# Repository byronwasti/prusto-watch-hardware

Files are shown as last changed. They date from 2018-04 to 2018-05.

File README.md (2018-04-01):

# Prusto Watch Hardware
Hardware for the Prusto Watch

# Update Log

## 0.3.0
- Chip now has USB functionality
- Moved to an accelerometer instead of an IMU
- New PMIC chip
- Smaller layout with mounting holes

## 0.2.0
- Chip selected has no USB functionality
- LEDs work
- Battery connector is incorrect
- BLE is functional
- Display connector is flipped (must be soldered on backwards)

## 0.1.0
- Poor debuggability
- BLE connectivity
- IMU routing
- LED
- Display

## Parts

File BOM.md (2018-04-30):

# Prusto Watch BOM

Manufacturer Part Number | Description | Digikey | Count | Price
:---|:---|:---|---: | ---:
RJD3032HPPV30M | Battery | 1572-1623-ND | 1 | 16.71 
Molex 0532610271 | Battery Connector | WM7620CT-ND | 1 | 0.93
MCP73831T-2ACI/OT | Battery Charger | MCP73831T-2ACI/OT | 1 | 0.59
TPS2113ADRBR | Power Multiplexer | 296-46373-1-ND | 1 | 2.01
TPS70933DBVR | 3.3V Voltage Regulator | 296-35483-1-ND | 1 |  1.17
LS010B7DH01 | OLED Screen | 425-2899-ND | 1 | 22.88
Molex LLC 5034801000 | FPC Screen Connector | WM1389CT-ND | 1 | 0.93
TPS60241DGKR | 5V Charge Pump | 296-12241-6-ND | 1 | 1.65
STM32F303C8T6 | Arm Cortex-M4 MCU | 497-15198-ND | 1 | 4.49
FA-238 16.0000MB-C3 | 16MHz Crystal | SER3686CT-ND | 1 | 0.43
ECS-.327-12.5-34B-TR | RTC Crystal | XC1617CT-ND  | 1 | 0.54
SMLP34RGB2W3 | 3-Color LED | SMLP34RGB2W3CT-ND | 1 | 1.09
PTS820 J15M SMTR LFS | Push Button | CKN10506CT-ND | 2 | 0.44
LSM6DSLTR | IMU (Mag/Gyro/Acc) | 497-16705-1-ND | 1 | 4.09
RN4871-V | BLE Castellated Module | RN4871-V/RM118-ND | 1 | 7.45
RT9818A-18GV | Brown-Out Detector | RT9818A-18GV-ND | 1 | OUT
Adafruit Industries LLC 1201 | Vibration Motor | 1528-1177-ND | 1 | 1.95
C&K KXT 331 LHS | Tactile Switch | CKN10779CT-ND | 3 | 0.25

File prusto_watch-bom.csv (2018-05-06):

Reference | Quantity | Value | Footprint | Datasheet | Digikey
BT1 | 1 | RJD3032HPPV30M | Pin_Headers:Pin_Header_Straight_1x02_Pitch1.27mm |  | 1572-1623-ND
C1 C2 | 2 | 12.5pF | Capacitors_SMD:C_0603
C17 C18 C19 C21 C24 C7 | 6 | 1uF | Capacitors_SMD:C_0603
C12 C25 C6 | 3 | 10uF | Capacitors_SMD:C_0805
C3 C4 | 2 | 18pF | Capacitors_SMD:C_0603
C8 | 1 | 2.2uF | Capacitors_SMD:C_0603
C10 C11 C13 C14 C15 C16 C20 C26 C9 | 9 | 100nF | Capacitors_SMD:C_0603
D1 D2 D4 | 3 | LED | LEDs:LED_0603
FP1 | 1 | RN4871 | prusto_watch:BM71BLES1FC2
J1 | 1 | USB_microB_2040002-1 | prusto_watch:USB_microB_2040002-1 |  | TODO
J2 | 1 | Conn_02x05_Odd_Even | Pin_Headers:Pin_Header_Straight_2x05_Pitch1.27mm
J3 | 1 | Vibration Motor | Pin_Headers:Pin_Header_Straight_1x02_Pitch1.27mm
J4 J5 | 2 | Conn_01x06 | Pin_Headers:Pin_Header_Straight_2x03_Pitch1.27mm
J6 | 1 | Conn_02x03_Odd_Even | Pin_Headers:Pin_Header_Straight_2x03_Pitch1.27mm
J7 | 1 | Conn_02x03_Counter_Clockwise | Pin_Headers:Pin_Header_Straight_2x03_Pitch1.27mm
Q3 | 1 | RUM002N02T2L | prusto_watch:VMT3
R13 R6 | 2 | 100K | Resistors_SMD:R_0603
R14 | 1 | 4.75K | Resistors_SMD:R_0603
R1 R15 R4 | 3 | 1K | Resistors_SMD:R_0603
R16 R2 R3 | 3 | 10K | Resistors_SMD:R_0603
R5 | 1 | 301K | Resistors_SMD:R_0603
U1 | 1 | STM32F303RCT6-48 | Housings_QFP:LQFP-48_7x7mm_Pitch0.5mm |  | 497-15198-ND
U2 | 1 | LTC4063 | prusto_watch:DFN-10-1EP_3x3mm_Pitch0.5mm
U3 | 1 | LIS3DETR | prusto_watch:16-LGA_(3x3)
U5 | 1 | TPS60241DGKR | Housings_SSOP:MSOP-8_3x3mm_Pitch0.65mm |  | TODO
U7 | 1 | RT9818A-18GV | TO_SOT_Packages_SMD:SOT-23
U8 | 1 | WM1389CT-ND | prusto_watch:Molex_FPC_5034801000
Y1 | 1 | ECS.327 | prusto_watch:ECX-31B
Y2 | 1 | FA-238 | Crystals:Crystal_SMD_SeikoEpson_FA238V-4pin_3.2x2.5mm

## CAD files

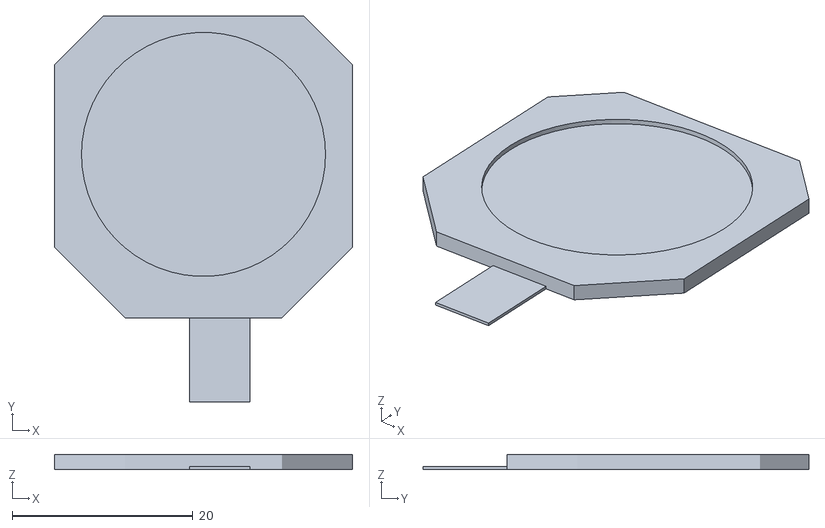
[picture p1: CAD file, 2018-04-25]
case/display.stl
33.0 x 42.7 x 1.64

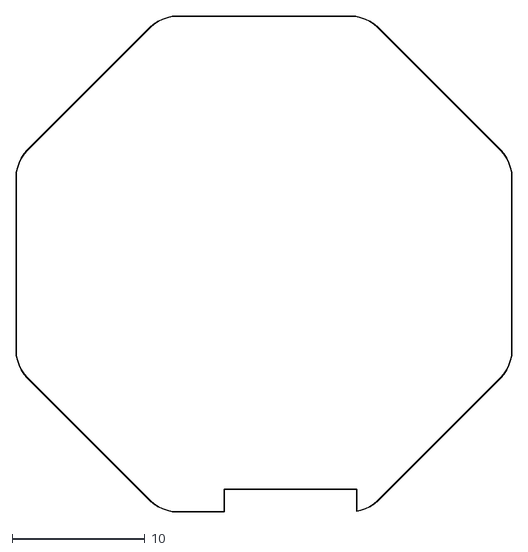
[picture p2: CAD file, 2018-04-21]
case/pcb-shape.dxf
37.4 x 37.4

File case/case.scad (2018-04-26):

use <util.scad>
use <components.scad>

$fn = 10;

/* Module Definitions */

module bottom_frame(r, h, wt=1) {
    translate([0, 0, h/2])
    union() {
        linear_extrude(height=h) {
            projection(cut=true) {
                translate([0, 0, 0.1])
                    rounded_octagon_2(r, h);
            }
        }

        difference() {
            rounded_octagon_2(r, h);
            translate([-r, -r, 0]) cube([r*2, r*2, h*5]);
        }   
    }
}

module bottom_frame_cutout(r, h, wt=1) {
    translate([0, 0, h/2])
    union() {
        linear_extrude(height=h) {
            projection(cut=true) {
                translate([0, 0, 0.1])
                    rounded_octagon_2(r-wt, h);
            }
        }

        difference() {
            rounded_octagon_2(r-wt, h);
            translate([-r, -r, 0]) cube([r*2, r*2, h*5]);
        }   
    }
}

module bottom_usb_cutout(w=4, h=3) {
    difference() {
        cube([10, 7, 3], center=true);
        translate([0, -6, 3]) rotate([45, 0, 0]) cube([11, 10, 8], center=true);
        translate([0, 6, 3]) rotate([-45, 0, 0]) cube([11, 10, 8], center=true);
    }
}

module bottom_clips(r, length, dist) {
    for(i = [45, -45, 180]) {
        rotate([0, 0, i])
            translate([0, dist, 0])
            rotate([0, 90, 0])
            difference() {
                //capped_cylinder(r=r, h=length);
                cylinder(r=r, h=length, center=true);
                translate([0, -length, 0])
                    cube([length*2, length*2, length*2], center=true); 
            }
    }
}

module bottom_harness() {
    for(i = [-1, 1]) {
        for(j = [-1, 1]) {
            hull() {
                translate([j*6, i*21, 4])
                    rotate([i*45, 0, 0])
                    cylinder(r=1, h=8, center=true);

                translate([j*6, i*21, 1])
                    rotate([90, 0, 0])
                    cylinder(r=1, h=6, center=true);
            }
        }

        translate([0, i*24, 1])   
            rotate([0, 90, 0])
            cylinder(r=1, h=13, center=true);
    }

}

// Radius, height, wallthickness
module bottom(r, h, wt=1) {
        
    difference() {
        union() {
            translate([0, 0, 5])
                bottom_clips(2, 12, cos(22.5) * (r));

            bottom_harness();
            bottom_frame(r, h, wt);
        }

        translate([0, 0, 5])
           bottom_clips(1, 10, cos(22.5) * (r-1));

        translate([0, 0, 1]) bottom_frame_cutout(r, h, wt);
        
        translate([-20, -3, 5]) bottom_usb_cutout();

        // Jtag cutout
        translate([-15, -15, 3]) rotate([0, 0, 45]) cube([6, 6, 3], center=true);
    }
}

module top_clips(r, length, dist) {
    for(i = [45, -45, 180]) {
        rotate([0, 0, i])
        translate([0, dist, 0])
            difference() {
                translate([0, 0, 1])
                cube([8, 2, 6], center = true);

                translate([0, -3, 8])
                    rotate([30, 0, 0])
                    cube([10, 10, 10], center=true);

                translate([0, 1, 0])
                    rotate([0, 90, 0])  
                    cylinder(r = 1.3, h = 10, center=true);
            }
    }
}


// Radius height wallthickness
module top(r, h, wt=1) {
    union() {
        translate([0, 0, -4])
            top_clips(2, 12, cos(22.5) * 21);

        translate([0, 0, -h])
            linear_extrude(height=h) {
                projection(cut=true) {
                    translate([0, 0, 0.1])
                        hollowed_octagon(r, h, wt);
                }
        }

        difference() {
            hollowed_octagon(r, h, wt);
            translate([0, 0, -(h*5)/2])
                cube([r*2, r*2, h*5], center=true);
            cylinder(r=27/2, h=10);
        }   
    }
}

module half_cut() {
    difference() {
        union() {
            translate([0, 0, 11]) top(22, 3);
            translate([0, 0, 0])bottom(22, 5);
        }

        translate([0, -25, 0]) cube([50, 50, 50]);
    }
}

module side_by_side() {
    $fn=40;
    union() {
        bottom(22, 5);
        translate([0, 50, 2.5]) rotate([0, 180, 0]) top(22, 3);
    }
}


/* Global Variables */

radius = 20;
bottom_height = 6;
thickness = 1;


/* Main Objects */

//translate([0, 0, 5]) battery();
//translate([0, 0, 10]) pcb();
translate([0, 0, 0]) rotate([0, 0, 180]) display();
translate([0, 0, 15]) top(22, 3);
translate([0, 0, -15])bottom(22, 5);

//!half_cut();

!side_by_side();

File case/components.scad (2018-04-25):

module pcb() {
    difference() {
        rounded_hex(17, 2);
        translate([2, -19, 0]) cube([10, 4, 10], center=true);
    }
}

module battery() {
    color([1, 0, 1, 1])
    cylinder(h=3.4, r=15, center=true);
}


module display() {
    color([1, 0, 0, 1])
    translate([-16.5, 16, 0])
    import("display.stl");
}

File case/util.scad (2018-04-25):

module rounded_hex(r, h) {
    rotate([0, 0, 22.5])
    hull(){
        for (i=[0:8]) {
            rotate([0, 0, i*45])
            translate([r, 0, 0])
                cylinder(h=h, r=3, center=true);
        }
    }
}

// radius, height, corner-radius
module rounded_octagon(r, h, cr) {
    rotate([0, 0, 22.5])
    hull(){
        for (i=[0:7]) {
            rotate([0, 0, i*45])
            translate([(r - cr), 0, 0])
                cylinder(h=h, r=cr, center=true);
        }
    }
}

// radius, height
module rounded_octagon_2(r, h) {
    hull() {
        for (i=[0:7]) {
            rotate([0, 0, i*45])
                translate([cos(22.5) * (r-h/2), 0, 0])
                rotate([90, 0, 0])
                cylinder(h = 2 * (r - h/2) * cos(67.5),
                        r = h / 2,
                        center = true);
        }
    }
}

module rounded_box(dim, r) {
    minkowski() {
        cube(dim, center=true);
        sphere(r=r);
    }
}

module hollowed_octagon(r, h, wt=1) {
    difference() {
        translate([]) rounded_octagon_2(r, 5);
        rounded_octagon_2(r-wt, 2);
    }
}

module capped_cylinder(r, h) {
    cylinder(r=r, h=(h-2*r), center=true);
    translate([0, 0, -(h-2*r)/2])
        sphere(r=r);
    translate([0, 0, (h-2*r)/2])
        sphere(r=r);
}

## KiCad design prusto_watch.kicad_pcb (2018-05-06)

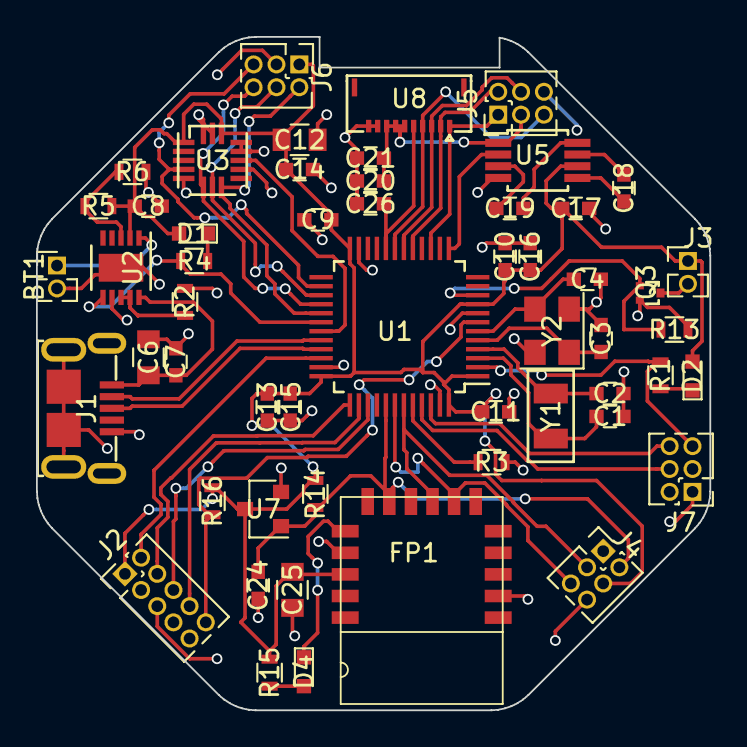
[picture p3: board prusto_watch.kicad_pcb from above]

Board: 2 copper layers, 37.4 x 37.4 mm, 54 parts (0 on the bottom side), 47 nets.

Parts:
BT1: RJD3032HPPV30M; Pin_Header_Straight_1x02_Pitch1.27mm
C1, C2: 12.5pF; C_0603
C3, C4: 18pF; C_0603
C6, C12, C25: 10uF; C_0805
C7, C17, C18, C19, C21, C24: 1uF; C_0603
C8: 2.2uF; C_0603
C9, C10, C11, C13, C14, C15, C16, C20, C26: 100nF; C_0603
D1, D2, D4: LED; LED_0603
FP1: RN4871; BM71BLES1FC2
J1: USB_microB_2040002-1
J2: Conn_02x05_Odd_Even; Pin_Header_Straight_2x05_Pitch1.27mm
J3: Vibration Motor; Pin_Header_Straight_1x02_Pitch1.27mm
J4, J5: Conn_01x06; Pin_Header_Straight_2x03_Pitch1.27mm
J6: Conn_02x03_Odd_Even; Pin_Header_Straight_2x03_Pitch1.27mm
J7: Conn_02x03_Counter_Clockwise; Pin_Header_Straight_2x03_Pitch1.27mm
Q3: RUM002N02T2L; VMT3
R1, R4, R15: 1K; R_0603
R2, R3, R16: 10K; R_0603
R5: 301K; R_0603
R6, R13: 100K; R_0603
R14: 4.75K; R_0603
U1: STM32F303RCT6-48; LQFP-48_7x7mm_Pitch0.5mm
U2: LTC4063; DFN-10-1EP_3x3mm_Pitch0.5mm
U3: LIS3DETR; 16-LGA_(3x3)
U5: TPS60241DGKR; MSOP-8_3x3mm_Pitch0.65mm
U7: RT9818A-18GV; SOT-23
U8: WM1389CT-ND; Molex_FPC_5034801000
Y1: ECS.327; ECX-31B
Y2: FA-238; Crystal_SMD_SeikoEpson_FA238V-4pin_3.2x2.5mm

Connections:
+3V3: C8.1, C9.1, C10.1, C11.1, C12.1, C13.1, C14.1, C15.1, C16.1, C17.1, C25.2, D1.2, D2.2, FP1.14, J2.1, J3.1, J4.4, J6.1, R5.1, R14.1, R15.1, R16.1, U1.1, U1.9, U1.24, U1.36, U1.48, U2.2, U3.1, U3.14, U5.6, U7.3
+5V: C20.1, C21.1, J5.3, U5.1, U8.6, U8.7, U8.8
/5V_EN: U1.13, U5.2
/ACC_CS: J6.2, U1.29, U3.8
/ACC_INT1: U1.31, U3.11
/ACC_SCK: J6.5, U1.26, U3.4
/ACC_SDI: J6.6, U1.28, U3.6
/ACC_SDO: J6.4, U1.27, U3.7
/BLE_nRST: C24.1, FP1.10, J4.2, R14.2, U1.41, U7.1
/BUTTON1: J7.4, U1.45
/BUTTON2: J7.6, U1.46
/CHRG_STAT: R4.2, U1.30, U2.6
/DISP_EN: C26.1, U1.20, U8.5
/DISP_SCLK: J5.1, U1.15, U8.1
/DISP_SCS: J5.4, U1.18, U8.3
/DISP_SDI: J5.2, U1.17, U8.2
/EXTCOMIN: J5.5, U1.19, U8.4
/LED_1: J7.5, R1.2, U1.2
/MOTOR_EN: Q3.1, R13.1, U1.10
/RX_BLE: FP1.7, J4.5, U1.42
/STM_NRST: J2.10, R16.2, U1.7
/TCK: J2.4, U1.37
/TDI: J2.8, U1.38
/TDO: J2.6, U1.39
/TMS: J2.2, U1.34
/TX_BLE: FP1.8, J4.3, U1.43
/USB_N: J1.2, U1.32
/USB_P: J1.3, U1.33
GND: BT1.2, C1.2, C2.2, C3.2, C4.2, C6.2, C7.2, C8.2, C9.2, C10.2, C11.2, C12.2, C13.2, C14.2, C15.2, C16.2, C17.2, C20.2, C21.2, C24.2, C25.1, C26.2, FP1.2, FP1.13, J1.5, J1.6, J1.7, J1.8, J1.9, J1.10, J1.11, J2.3, J2.5, J4.6, J5.6, J6.3, J7.1, J7.2, J7.3, Q3.2, R2.2, R3.2, R6.2, R13.2, U1.8, U1.23, U1.35, U1.47, U2.7, U2.11, U3.5, U3.10, U3.12, U3.13, U3.15, U3.16, U5.4, U7.2, U8.9, U8.10, Y2.2, Y2.4
unnamed: BT1.1, U2.1
unnamed: C1.1, U1.3, Y1.2
unnamed: C2.1, U1.4, Y1.1
unnamed: C3.1, U1.5, Y2.1
unnamed: C4.1, U1.6, Y2.3
unnamed: C6.1, C7.1, J1.1, U2.10
unnamed: C18.1, U5.7
unnamed: C18.2, U5.5
unnamed: C19.1, U5.8
unnamed: C19.2, U5.3
unnamed: D1.1, R4.1
unnamed: D2.1, R1.1
unnamed: D4.1, FP1.12
unnamed: D4.2, R15.2
unnamed: J3.2, Q3.3
unnamed: R2.1, U2.8, U2.9
unnamed: R3.1, U1.44
unnamed: R5.2, R6.1, U2.3

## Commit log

2018-01-31 Add intial files
    [OpenWatch.kicad_pcb, OpenWatch.sch]
2018-02-09 Rename to Prusto Watch
    [prusto_watch.kicad_pcb, prusto_watch.sch]
2018-02-09 Remove external touch-sensor chip dependency
    [prusto_watch.sch]
2018-02-12 Rework component list
    [prusto_watch.sch]
2018-02-12 Basic positioning
    [prusto_watch.kicad_pcb, prusto_watch.sch]
2018-02-13 Remove battery control circuitry
    [prusto_watch.sch]
2018-02-20 Add debug lines and TSC lines
    [prusto_watch.sch]
2018-02-20 Update footprints
    [prusto_watch.kicad_pcb, prusto_watch.sch]
2018-02-20 Finish basic placement
    [prusto_watch.kicad_pcb, prusto_watch.sch]
2018-02-23 Finish routing traces
    [prusto_watch.kicad_pcb, prusto_watch.sch]
2018-03-25 Update schematic and README
    [prusto_watch.sch]
2018-03-25 Fix footprint for FPC connector
    [prusto_watch.kicad_pcb]
2018-03-29 Add new accelerometer and PMIC to library
2018-03-29 Modify schematic
    [prusto_watch.kicad_pcb, prusto_watch.sch]
2018-03-30 Finish schematic for v3
    [prusto_watch-bom.csv, prusto_watch.kicad_pcb, prusto_watch.sch]
2018-03-30 Modify names
    [prusto_watch.sch]
2018-03-30 First pass at PCB placement
    [prusto_watch.kicad_pcb, prusto_watch.sch]
2018-03-30 Modify for better positioning
    [prusto_watch.kicad_pcb]
2018-04-01 Rework placement
    [prusto_watch.kicad_pcb, prusto_watch.sch]
2018-04-01 Switch PMIC with USB input
    [prusto_watch.kicad_pcb, prusto_watch.sch]
2018-04-01 Finalize Routing
    [prusto_watch.kicad_pcb, prusto_watch.sch]
2018-04-01 Add logos
    [prusto_watch.kicad_pcb]
2018-04-01 Widen power traces
    [prusto_watch.kicad_pcb]
2018-04-21 Update schematic and PCB shape
    [Case-new.scad, pcb-shape.dxf, prusto_watch-bom.csv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]
2018-04-23 Update board layout
    [prusto_watch.kicad_pcb, prusto_watch.sch]
2018-04-23 Breakout EXTCOMIN instead of 5Ven
    [prusto_watch.kicad_pcb, prusto_watch.sch]
2018-04-23 Update silkscreen
    [prusto_watch.kicad_pcb]
2018-04-24 Finish v0.4
    [prusto_watch.kicad_pcb, prusto_watch.sch]
2018-04-25 Update Case
    [Case-new.scad]
2018-04-25 Update case code style
    [Case-new.scad, case.scad, components.scad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]
2018-04-25 Update to case
    [case.scad]
2018-04-26 Add case v2
    [case.scad]
2018-04-30 Update BOM with button
2018-05-06 Small changes
    [prusto_watch-bom.csv, prusto_watch.kicad_pcb]
